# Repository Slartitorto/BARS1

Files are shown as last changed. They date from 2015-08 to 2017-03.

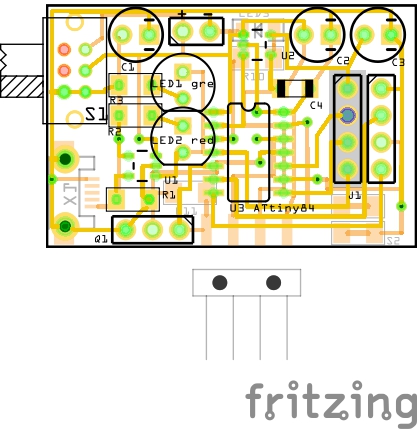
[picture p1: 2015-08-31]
HARDWARE/sensor/1.65/BARS1_1.65_PCB.jpg

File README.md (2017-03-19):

# BARS1
BAsic Remote Sensors vers. 1

BARS1_firmware is the sketch for ATtiny84a as trasmitter (Hooly)<BR>
ESP2866_receiver is the sketch for ESP8266-07 as receiver (Hooly-router)<BR>
simple_receiver.cpp is the very simple demo test for RaspberryPi as receiver<BR>
BARS1_receiver.cpp is the complete c++ software for RaspberrtPi as receiver<BR>
<BR>
WEB folder contains all you need to receive, manage and show data on the remote server<BR>
HARDWARE folder contains Fritzing source, gerber and pdf file for sensor and ESP8266 receiver, autodesk 123D design Hooly case<BR>

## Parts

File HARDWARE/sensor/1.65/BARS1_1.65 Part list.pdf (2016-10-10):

Pos | Componente | Prezzo | Vendor | Cod. Vendor
U3 | Microcontroller ATTINY84A-SSU | 1,29 | Mouser.com | 556-ATTINY84A-SSU (http://www.mouser.it/ProductDetail/Atmel/ATTINY84A-SSU/?qs=sGAEpiMZZMvqv2n3s2xjsUVXpvE2IBMzcgbJdwhGYzI%3d)
| Zoccolo 8 pin | 0,09 | Mouser.com | 571-1-2199298-2 (http://www.mouser.it/Search/ProductDetail.aspx)
| Modulo radio nRF24L01+ | 0,85 | Aliexpress | ND (http://it.aliexpress.com/item/NRF24L01-NRF24L01-Wireless-Module-2-4G-Wireless-Communication-Module-Upgrade-Module/1998276323.html)
Led1 | Led verde | 0,10 | Mouser.com | 859-LTL1CHJGTNN (https://www.mouser.it/Search/ProductDetail.aspx)
Led2 | Led rosso | 0,07 | Mouser.com | 859-LTL-1CHEE (https://www.mouser.it/Search/ProductDetail.aspx?R=LTL-1CHEEvirtualkey57820000virtualkey859-LTL-1CHEE)
Led3 | Led verde smd | 0,28 | Mouser.com | 859-LTST-C230GKT (https://www.mouser.it/Search/ProductDetail.aspx)
U2 | regolatore LDO MIC5205-3.3YM5 | 0,48 | Mouser.com | 998-MIC5205-3.3YM5TR
C4 | Condensatore 470 pF SMD | 0,09 | Mouser.com | 77-VJ1206Y471KXJPBC (https://www.mouser.it/Search/ProductDetail.aspx)
C2 | Condensatore elettr. 10uF 35V 5x7 | 0,10 | Mouser.com | 647-USA1V100MDD (https://www.mouser.it/Search/ProductDetail.aspx)
C3 | Condensatore elettr. 10uF 35V 5x7 | 0,10 | Mouser.com | 647-USA1V100MDD (https://www.mouser.it/Search/ProductDetail.aspx)
| PCB | 1,20 | SeeedStudio | ND (http://www.seeedstudio.com/service/index.php?r=pcb)
| Batteria ric. Li-Po 3,7V 350mAh | 2,18 | MiniInTheBox | 042035P (http://www.miniinthebox.com/it/3-7v-320mah-ai-polimeri-di-litio-per-telefoni-cellulari-mp3-mp4-4-20-35_p1590291.html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)
U1 | Caricabatteria MCP73831 | 0,53 | Mouser.com | 579-MCP73831T-2ATIOT (https://www.mouser.it/Search/ProductDetail.aspx)
S1 | Interruttore a scorrimento | 0,63 | Mouser.com | 612-EG2211 (https://www.mouser.it/Search/ProductDetail.aspx?R=EG2211virtualkey61200000virtualkey612-EG2211)
X1 | Connettore MicroUSB | 0,29 | Mouser.com | 649-10118193-0001LF (https://www.mouser.it/Search/ProductDetail.aspx)
C1 | Condensatore 4.7uF 16V | 0,11 | Mouser.com | 647-UMA1C4R7MCD2TP (https://www.mouser.it/Search/ProductDetail.aspx)
Q1 | Sensore di temperatura DS18B20+ | 2,52 | Mouser.com | 700-DS18B20+ (https://www.mouser.it/Search/ProductDetail.aspx)
S2 | Pulsante SMD | 0,21 | Mouser.com | 506-147873-1 (http://www.mouser.it/Search/ProductDetail.aspx?R=147873-1virtualkey50660000virtualkey506-147873-1)
R11 | Resistenza 4k7 SMD 1206 | 0,02 | RS Component | CRG1206F4K7 (http://it.rs-online.com/web/p/resistori-smd/2232350/)
R10 | Resistenza 2k2 SMD 1206 | 0,01 | RS Component | CRG1206F2K2 (http://it.rs-online.com/web/p/resistori-smd/2232300/)
R1 | Resistenza 3k3 SMD 1206 | 0,03 | RS Component | CRCW12063K30JNEA (http://it.rs-online.com/web/p/resistori-smd/8429241/)
R2 | Resistenza 4k7 SMD 1206 | 0,02 | RS Component | CRG1206F4K7 (http://it.rs-online.com/web/p/resistori-smd/2232350/)
R3 | Resistenza 4k7 SMD 1206 | 0,02 | RS Component | CRG1206F4K7 (http://it.rs-online.com/web/p/resistori-smd/2232350/)
| Totale | 11,22

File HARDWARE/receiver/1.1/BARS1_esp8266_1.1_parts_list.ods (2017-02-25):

C5 | Ceramic Capacitor | 0.1µF; package 1206
C6 | Ceramic Capacitor | 0.1µF; package 1206
C7 | Ceramic Capacitor | 0.1µF; package 1206
C10 | Electrolytic Capacitor | 330µF; voltage 16V
C11 | Electrolytic Capacitor | 470µF; voltage 16V
R2 | Resistor | 10kΩ | Pull-up CH-PD
R3 | Resistor | 10kΩ | Pull-up GPIO_2
R4 | Resistor | 10kΩ | Pull-up GPIO_0
R5 | Resistor | 1kΩ | Alim. LED Red
R7 | Resistor | 1kΩ | Alim. LED Green
R8 | Resistor | 10kΩ | Pull-up Reset
R9 | Resistor | 10kΩ | Pull-up GPIO_16
R10 | Resistor | 10kΩ | Pull-down GPIO_15
RED | LED | 3mm | H 12 mm
GRE | LED | 3mm | H 12 mm
U2 | AMS1117 | LDO Voltage regulator 3.3V -SOT223

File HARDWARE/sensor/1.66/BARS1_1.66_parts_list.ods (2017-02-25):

C1 | Electrolytic Capacitor | 4.7µF; voltage 16V
C2 | Electrolytic Capacitor | 10µF; voltage 16V
C3 | Electrolytic Capacitor | 10µF; voltage 16V
C5 | Ceramic Capacitor | 0.1µF; package 1206
C7 | Ceramic Capacitor | 470pF; package 1206 | x ByPass LDO
C8 | Ceramic Capacitor | 0.1µF; package 1206
DS2 | DS18B20 | part number DS18B20
R1 | Resistor | 5.6kΩ | Rprog per MCP73831
R10 | Resistor | 2.2kΩ | Alim. LED W
R11 | Resistor | 4.7kΩ | Alim. DS18B20
R12 | Resistor | 2.2kΩ | Alim. LED G
R13 | Resistor | 2.2kΩ | Alim. LED R
R14 | Resistor | 1kΩ | scarica condensatore
RED | LEDs | variant 1206; package led-1206
GRE | LEDs | variant 1206; package led-1206
WH | LEDs | variant 1206; package led-1206
U1 | MCP73831 | chip MCP73831; Li-ion/Li-poly
U2 | MIC5205 3.3 | LDO Voltage regulator
 | Ireg = 1000V/Rprog

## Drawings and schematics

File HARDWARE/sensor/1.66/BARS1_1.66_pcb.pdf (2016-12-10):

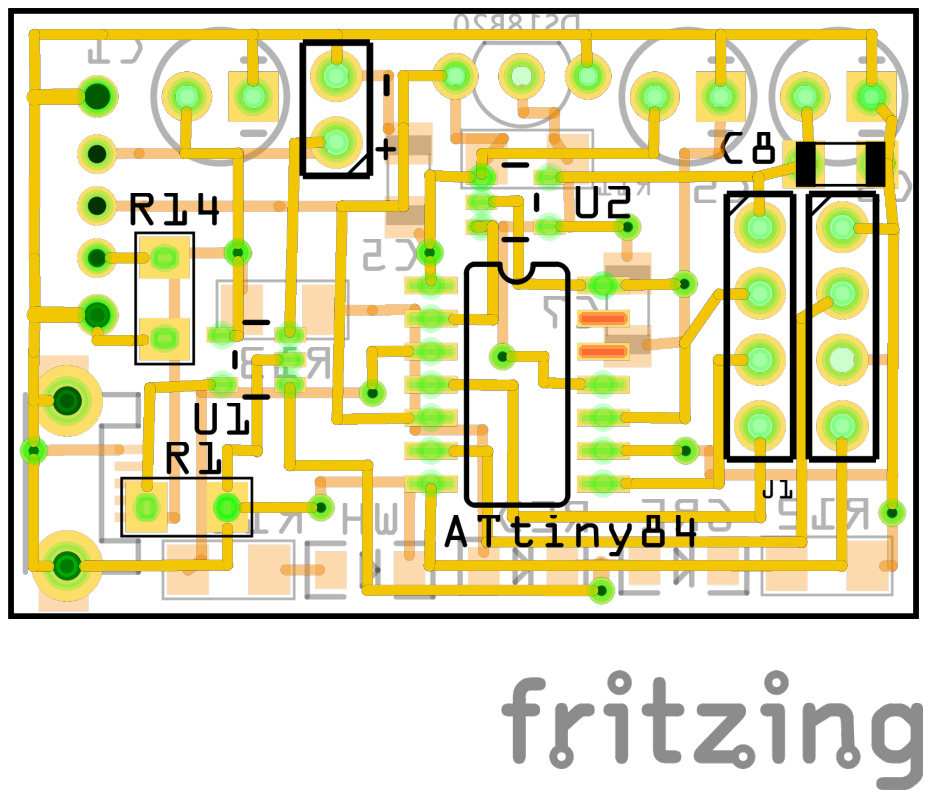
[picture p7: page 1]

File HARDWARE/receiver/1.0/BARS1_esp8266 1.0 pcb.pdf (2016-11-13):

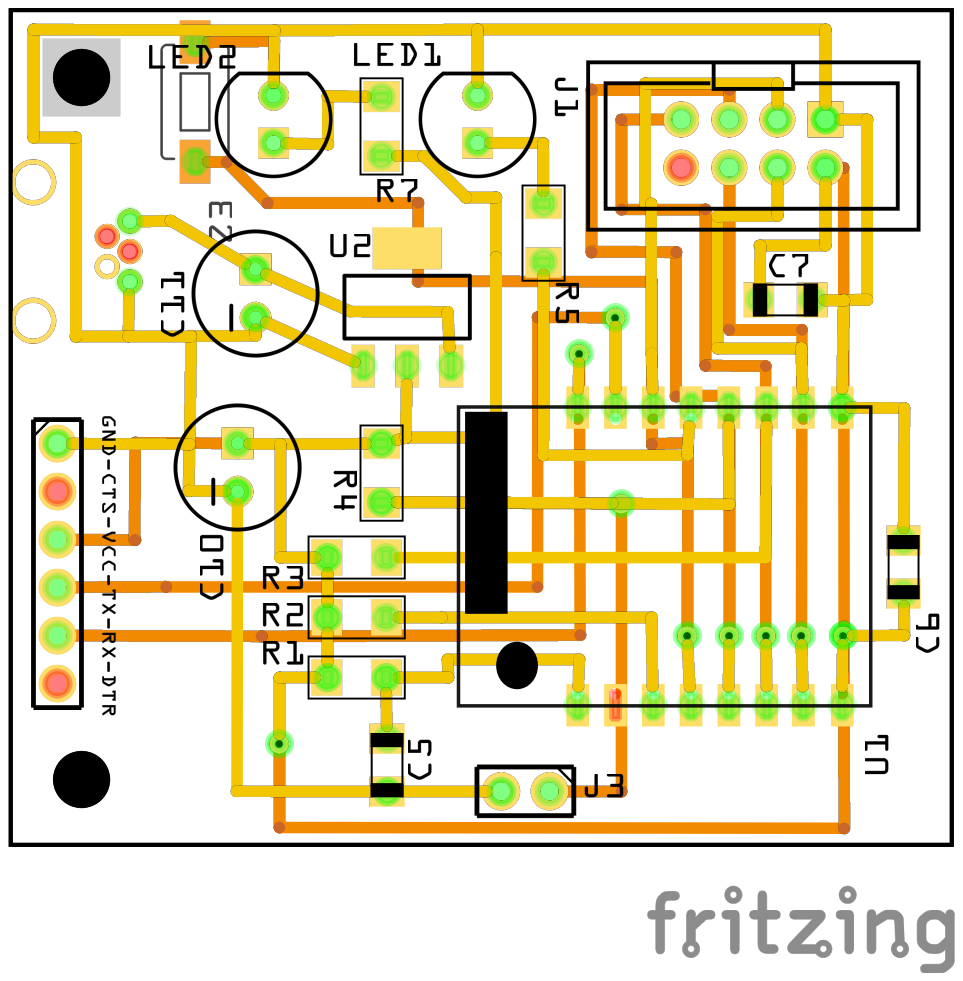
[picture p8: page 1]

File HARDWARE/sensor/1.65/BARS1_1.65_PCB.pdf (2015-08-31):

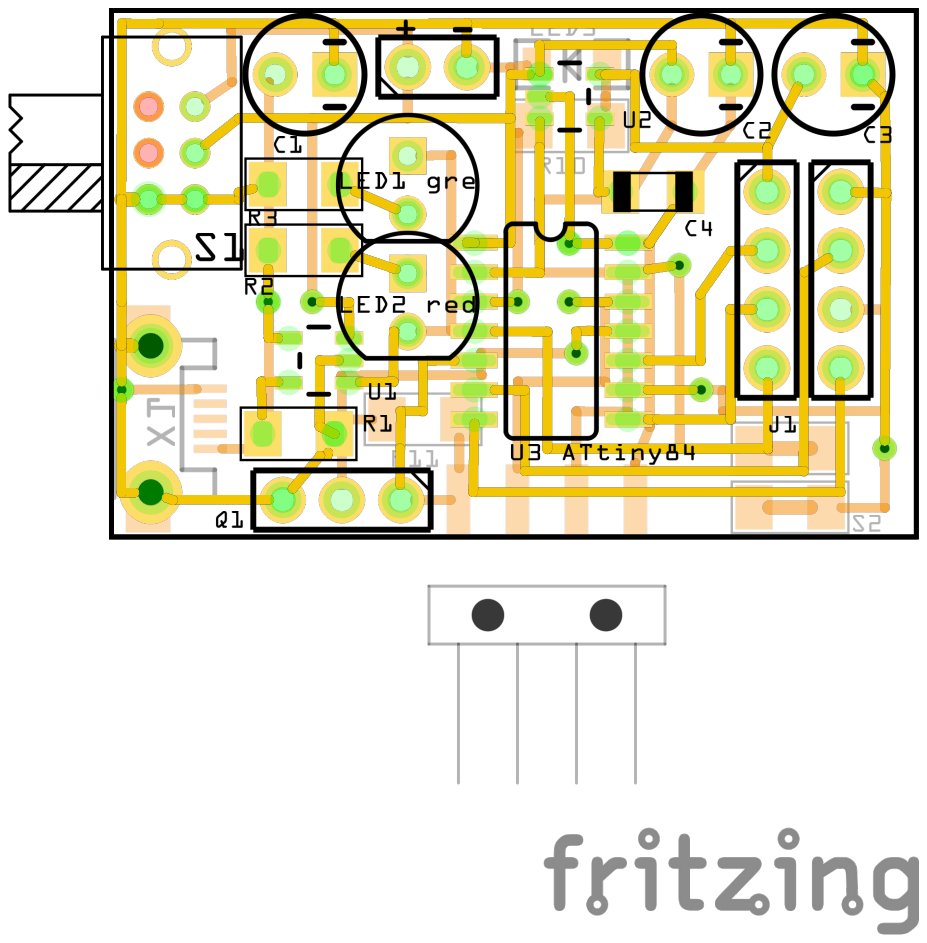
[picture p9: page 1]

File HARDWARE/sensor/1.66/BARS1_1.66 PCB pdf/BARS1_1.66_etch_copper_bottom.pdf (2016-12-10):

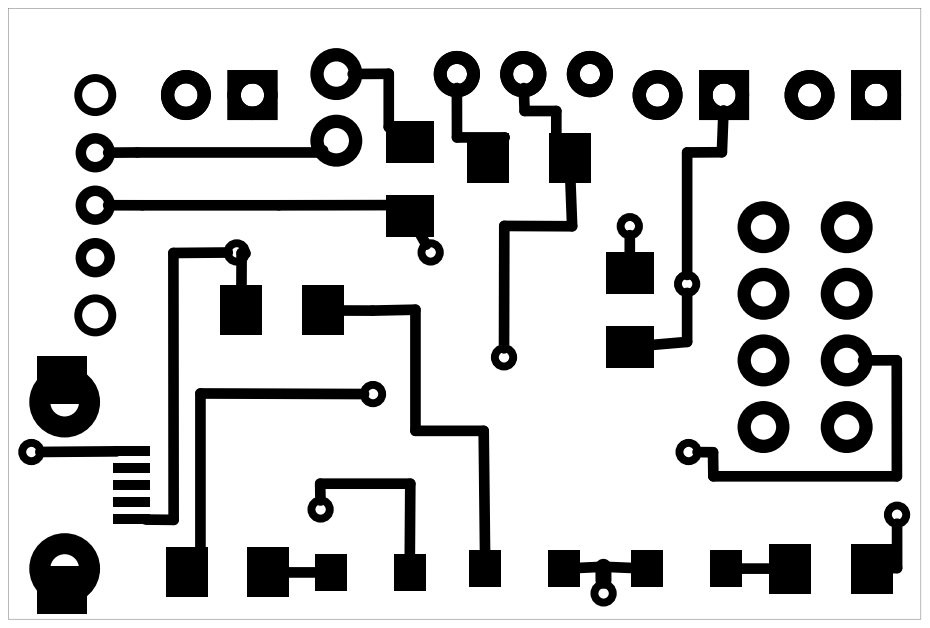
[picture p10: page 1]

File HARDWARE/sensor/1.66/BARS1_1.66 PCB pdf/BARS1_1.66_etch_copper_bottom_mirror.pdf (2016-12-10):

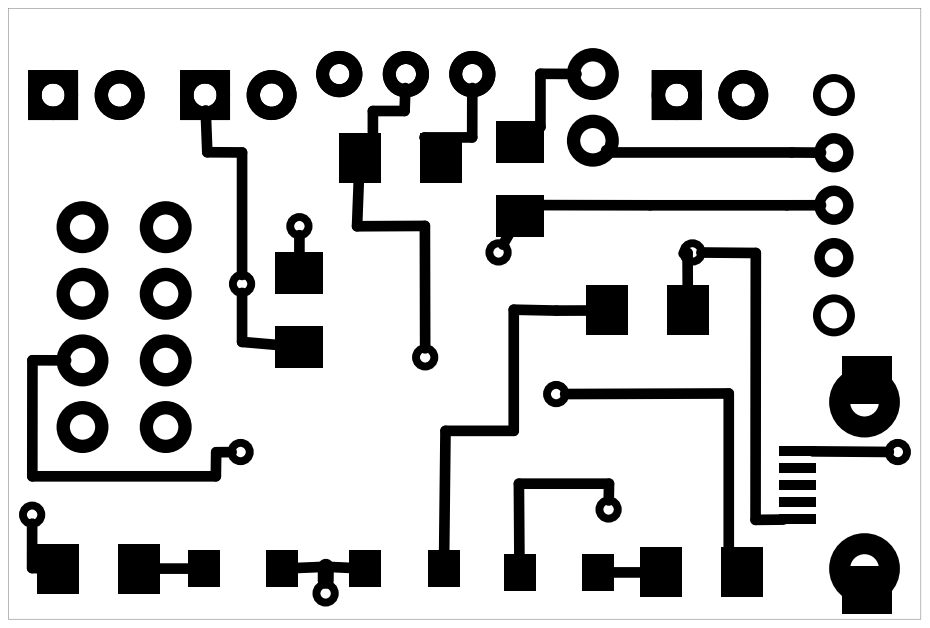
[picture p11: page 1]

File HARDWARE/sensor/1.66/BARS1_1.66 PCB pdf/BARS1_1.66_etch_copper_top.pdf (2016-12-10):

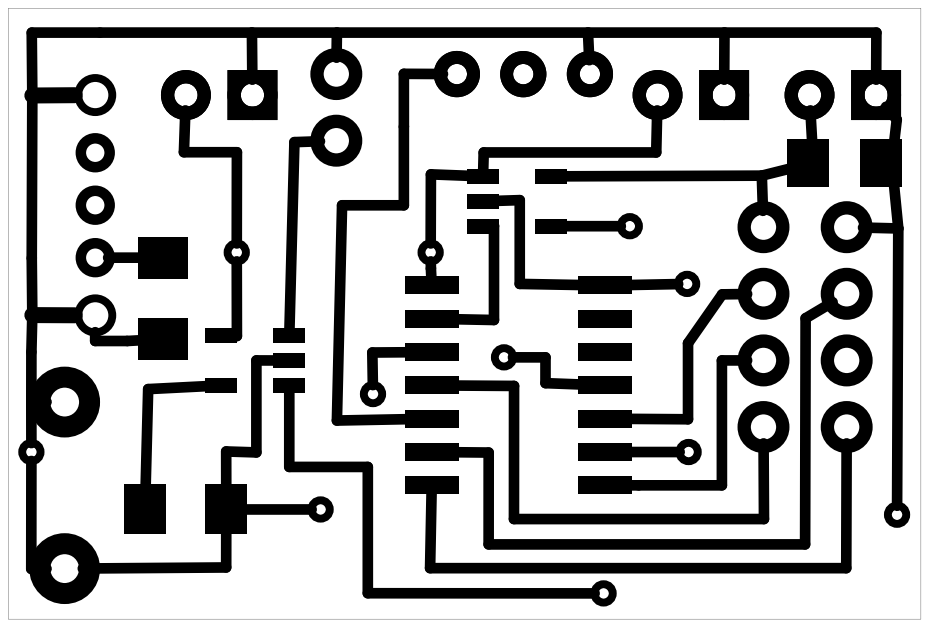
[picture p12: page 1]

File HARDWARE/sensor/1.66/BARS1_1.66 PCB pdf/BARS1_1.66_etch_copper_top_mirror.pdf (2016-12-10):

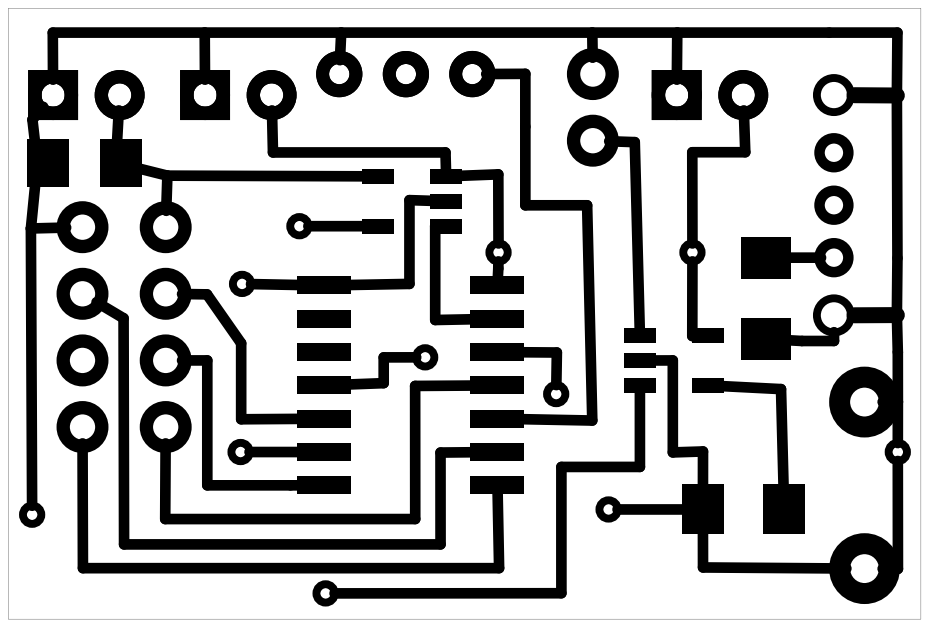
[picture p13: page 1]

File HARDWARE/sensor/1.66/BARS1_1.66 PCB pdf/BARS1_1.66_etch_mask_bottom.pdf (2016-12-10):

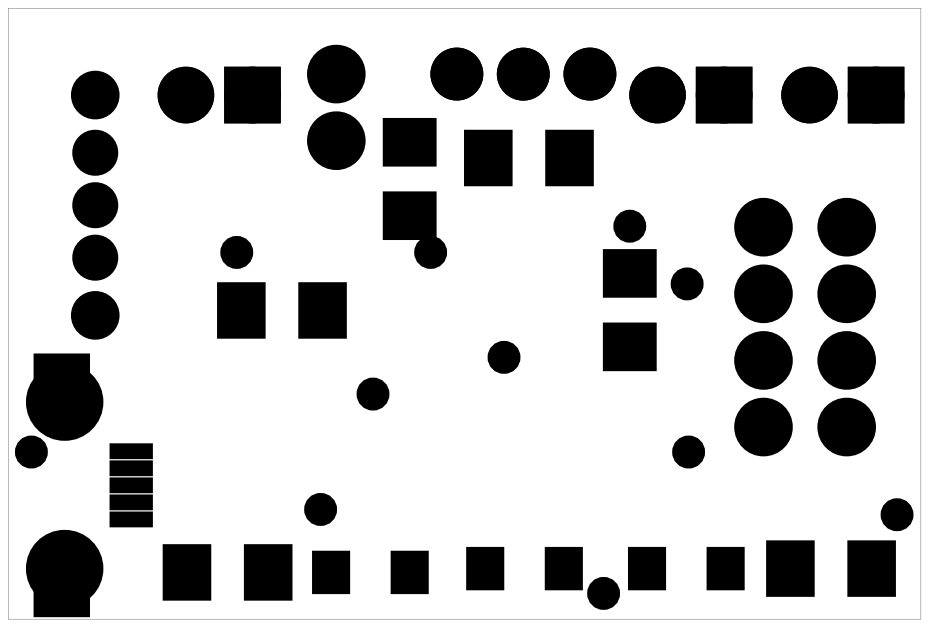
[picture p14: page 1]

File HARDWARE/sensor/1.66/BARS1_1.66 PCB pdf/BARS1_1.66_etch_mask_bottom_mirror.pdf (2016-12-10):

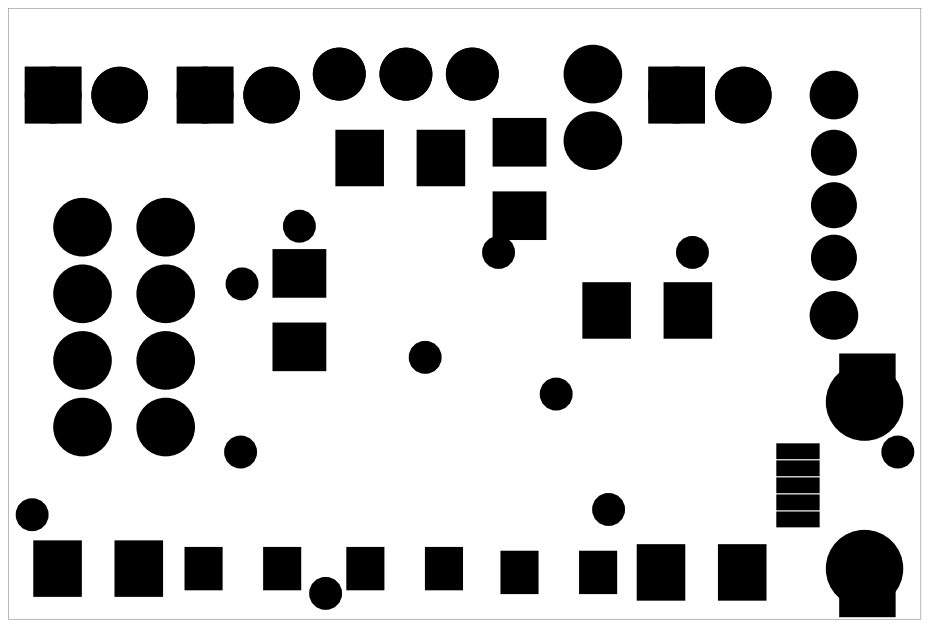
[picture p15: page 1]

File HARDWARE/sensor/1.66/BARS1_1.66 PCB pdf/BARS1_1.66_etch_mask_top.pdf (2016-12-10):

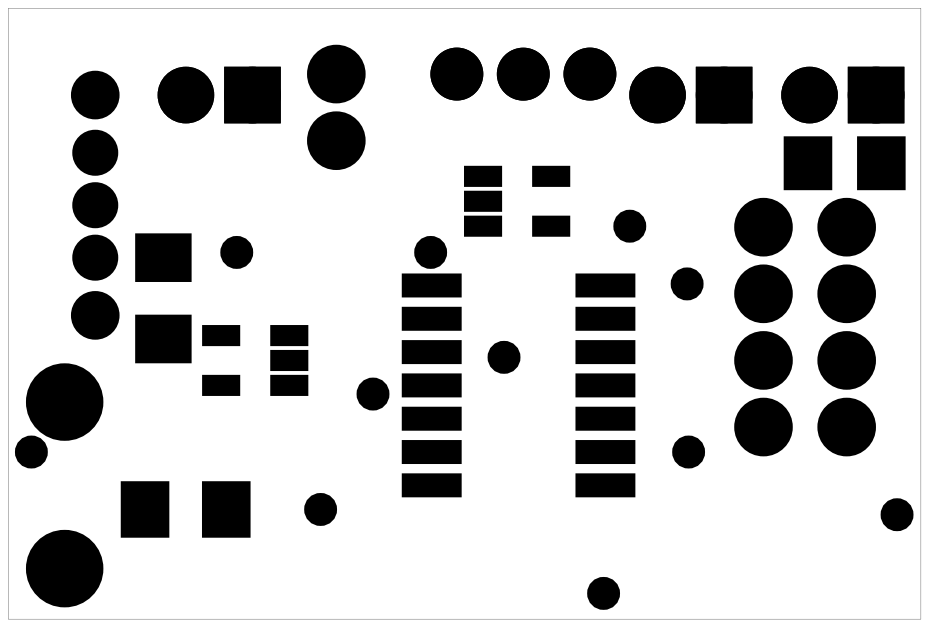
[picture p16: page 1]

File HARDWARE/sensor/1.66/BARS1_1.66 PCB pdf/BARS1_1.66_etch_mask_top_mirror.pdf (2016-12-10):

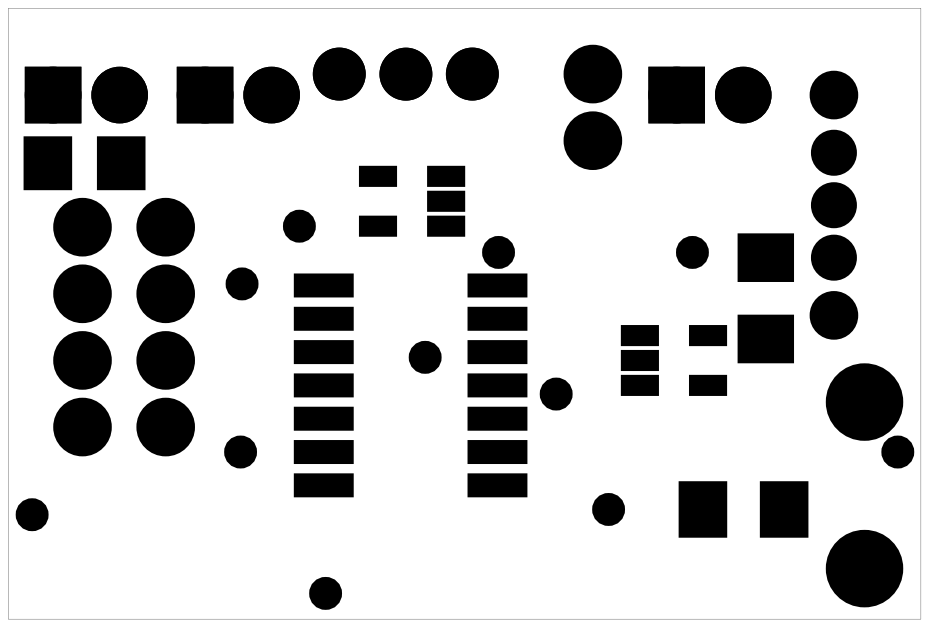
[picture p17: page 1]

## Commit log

2015-08-28 Reset after interrupt
2015-08-28 Simple receiver for RaspberryPi - for testing
2015-08-28 RaspberryPi Receiver
2015-08-31 Hardware info & spec.
    [BARS1_1.65.fzz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]
2015-12-21 Added space char as permitted char in the device_name and position
2016-07-22 gestisce i dati ricevuti dal raspberry
2016-09-05 razionalizzato il codice; nessuna variazione funzionale
    razionalizzato il codice; nessuna variazione funzionale
2016-09-05 Introdotta la tabella last_rec_data (contiene solo gli ultimi dati ricevuti) per velocizzare la pagina
2016-09-05 Introdotta la tabella last_rec_data per velocizzare la pagina status
2016-09-05 Il quality link si misura solo in base al ritardo 5xperiodo; eliminato il quality link sugli ultimi 100 dati. Molto più veloce
2016-09-05 Migliorato il codice, utilizzo la nuova tabella last_rec_data, aggiunti i limiti al grafico
2016-10-14 added pin connection specs
2016-11-02 Manual APmode in setup (in loop doesn’t work)
2016-11-13 Renaming files and add receiver
    [BARS1_1.65.fzz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]
2016-11-13 Adjusted comments on RF24 Pin connection
2016-12-10 receiver new version
    [BARS1_esp8266.fzz, BARS1_esp8266_1.1.fzz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]
2016-12-10 sensor hardware new version
    [BARS1_1.65.fzz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]
2016-12-10 min_ok and max_ok as option in device_details
2016-12-10 Added battery graph
2016-12-30 reload button go to correct url (temp graph)
2017-02-21 risolto bug: non resettava gli “alarmed” flag con serial alfanumerico
2017-02-25 Aggiunto Bill of Material
    [BARS1_1.66_parts_list.ods, BARS1_esp8266_1.1_parts_list.ods]
2017-03-06 Add home button
2017-03-26 Add sensor function
2017-04-07 Aumentato a 2,5 minuti il timeout per il controllo del keepalive
2017-04-08 added 45 ms delay on Voltage Regulator define setAutoAck and setRetries preparing radio set counter = 1 after period callback (avoid twice 0 and router get_period) simplified gotosleep and avoid abou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
2017-04-09 Battery alarm on 3.5V for Li-Po battery
2017-04-10 Adjusted battery percent due to Li-Po 3.5 need to recharge
2017-11-18 New PCB with atmega328
    [BARS1_2.0_beta0.fzz, BARS1_2.0_parts_list.ods]
2017-12-30 add “battery_alarmed flag”
2018-01-10 Add supply current sheet
    [Consumi BARS.ods]
2018-01-10 Removed obsolete
    [BARS1_2.0_beta0.fzz, BARS1_2.0_parts_list.ods]
2019-03-15 Update Consumi BARS.ods
    none
    [Consumi BARS.ods]
